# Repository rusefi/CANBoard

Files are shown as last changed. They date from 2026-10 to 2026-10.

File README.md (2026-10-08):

# CANBoard
CANBoard is a simple CAN enabled IO board, specifically designed to be used in devices like steering wheels/button boxes/panels/etc.

* 8 digital inputs
    * Ground switching
* 5 analog inputs
    * 5V max
* 4 digital outputs
    * Low side switch (open collector)
    * 0.5A max each
* STM32F303K8
* KiCad 7.0.0

# Goals
- Create a low cost device that my friends and I can use in our project cars
- Use components that are easily soldered by hand (hence 0805) and are preferably from my stock of frequently used parts (ex: LD1117S33CTR)
- Share my work with others for reference, inspiration or collaboration. 

If this project does help you in any way, I'd appreciate a message!

# [Store](https://dingo-electronics.square.site/product/canboard/3)

# Disclaimer
Please note that this product has been designed by a hobbyist, not a professional. It is intended for off-road and testing use only. Users should operate the product at their own discretion and risk. The designer explicitly disclaims any responsibility for damage or injury that may result from the use of this product.

# Schematic
[Schematic PDF](/Export/V2/CANBoard_HW_V2.pdf)

# DBC

DBC file can be found [here](https://github.com/corygrant/dingoFW/tree/master/dbc)

# BOM

[Interactive BOM](https://htmlpreview.github.io/?https://github.com/corygrant/CANBoard/blob/main/docs/bom/ibom.html)

# JLCPCB manufacturing export

With KiCad 10+ (`kicad-cli`) and Python 3 installed, run:

```bash
./bin/export_jlcpcb.sh
# Optional output directory:
./bin/export_jlcpcb.sh /path/to/output
```

The default output is the git-ignored `JLCPCB/` directory:

* `CANBoard-Gerbers.zip`: all four copper layers, masks, silkscreens, paste,
  outline and separate plated/non-plated Excellon drill files.
* `CANBoard-BOM.csv`: grouped by value, footprint and schematic `LCSC` field.
* `CANBoard-POS.csv`: component positions (CPL), in millimetres on both sides.

The BOM and POS contain matching populated SMD references. Through-hole parts,
logos, jumpers and other footprints without eligible positions are omitted.
Parts without an LCSC number remain in the assembly files with a warning.
Gerbers, drills and positions share the board's drill/place origin. Copper zones
are refilled during export without saving changes to the PCB.

The script works from any directory and does not depend on `hellen-one`.
Use `KICAD_CLI` or `PYTHON` to override executable paths. CSV headers follow
[JLCPCB's KiCad export guide](https://jlcpcb.com/help/article/how-to-generate-the-bom-and-centroid-file-from-kicad).
Rotations retain KiCad's orientation, normalized to 0–360 degrees; review part
matches and orientations in JLCPCB's assembly preview before ordering.

# Jumpers
**CAN Term** : Soldering this jumper enables the 120 ohm terminating resistor across CANL/CANH

**CAN ID Jumpers 1 and 2** : Soldering these jumpers allows different base CAN IDs to be selected when using multiple CANBoards in the same bus
| 1 | 2 | Base CAN ID (Hex)|
| --- | --- | ----- |
| Open | Open | 0x640 |
| Closed | Open | 0x650 |
| Open | Closed | 0x660 |
| Closed | Closed | 0x670 |

# Firmware
[dingoFW](https://github.com/corygrant/dingoFW)

# Updating Firmware
Use [Tag Connect TC2030 cable](https://www.tag-connect.com/product/tc2030-ctx-nl-stdc14-for-use-with-stm32-processors-with-stlink-v3) 

# Images
Top

Bottom

Connections

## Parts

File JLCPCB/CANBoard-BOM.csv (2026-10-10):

Comment | Designator | Footprint | LCSC Part #
10uF | C1,C2,C8 | C_0805_2012Metric | C15850
100nF | C3,C4,C7,C14,C17,C18,C19 | C_0805_2012Metric | C49678
22uF | C5,C6 | C_0805_2012Metric | C45783
10nF | C9,C10,C11,C12,C13,C21 | C_0805_2012Metric | C1710
27pF | C15,C16 | C_0805_2012Metric | C1808
4.7uF | C20 | C_0805_2012Metric | C1779
1uF | C22 | C_0805_2012Metric | C28323
LED_Small | D1 | LED_0805_2012Metric | C2900154
NUP2105LT1G | D2 | SOT-23-3 | C2890118
Ferrite_Bead_Small | FB1 | R_0805_2012Metric | C85840
5.6uH | L1 | Wuerth_LHMI | C467062
DMN2004WK | Q1,Q2,Q3,Q4 | SOT-323_SC-70 | C151011
30R | R1 | R_0805_2012Metric | C325808
52.3K | R2 | R_0805_2012Metric | C17740
10K | R3,R5,R6,R7,R8,R9,R10,R11,R12,R18,R19,R20,R21,R22,R24,R25,R26,R28,R29,R30,R31,R32,R33,R34,R35 | R_0805_2012Metric | C17414
120R | R4 | R_0805_2012Metric | C17437
4.7K | R13,R14,R15,R16,R17 | R_0805_2012Metric | C17673
1K | R23 | R_0805_2012Metric | C17513
120R 2W | R27 | R_2512_6332Metric | C19865
TPS56339DDCR | U1 | SOT-23-6 | C2071106
LD1117S33CTR | U2 | SOT-223 | C35879
MCP2562 | U3 | SOIC-8_3.9x4.9mm_P1.27mm | C191417
STM32F303K8T6 | U4 | LQFP-32_7x7mm_P0.8mm | C118318
8mHz | Y1 | Crystal_SMD_5032-2Pin_5.0x3.2mm | C144380

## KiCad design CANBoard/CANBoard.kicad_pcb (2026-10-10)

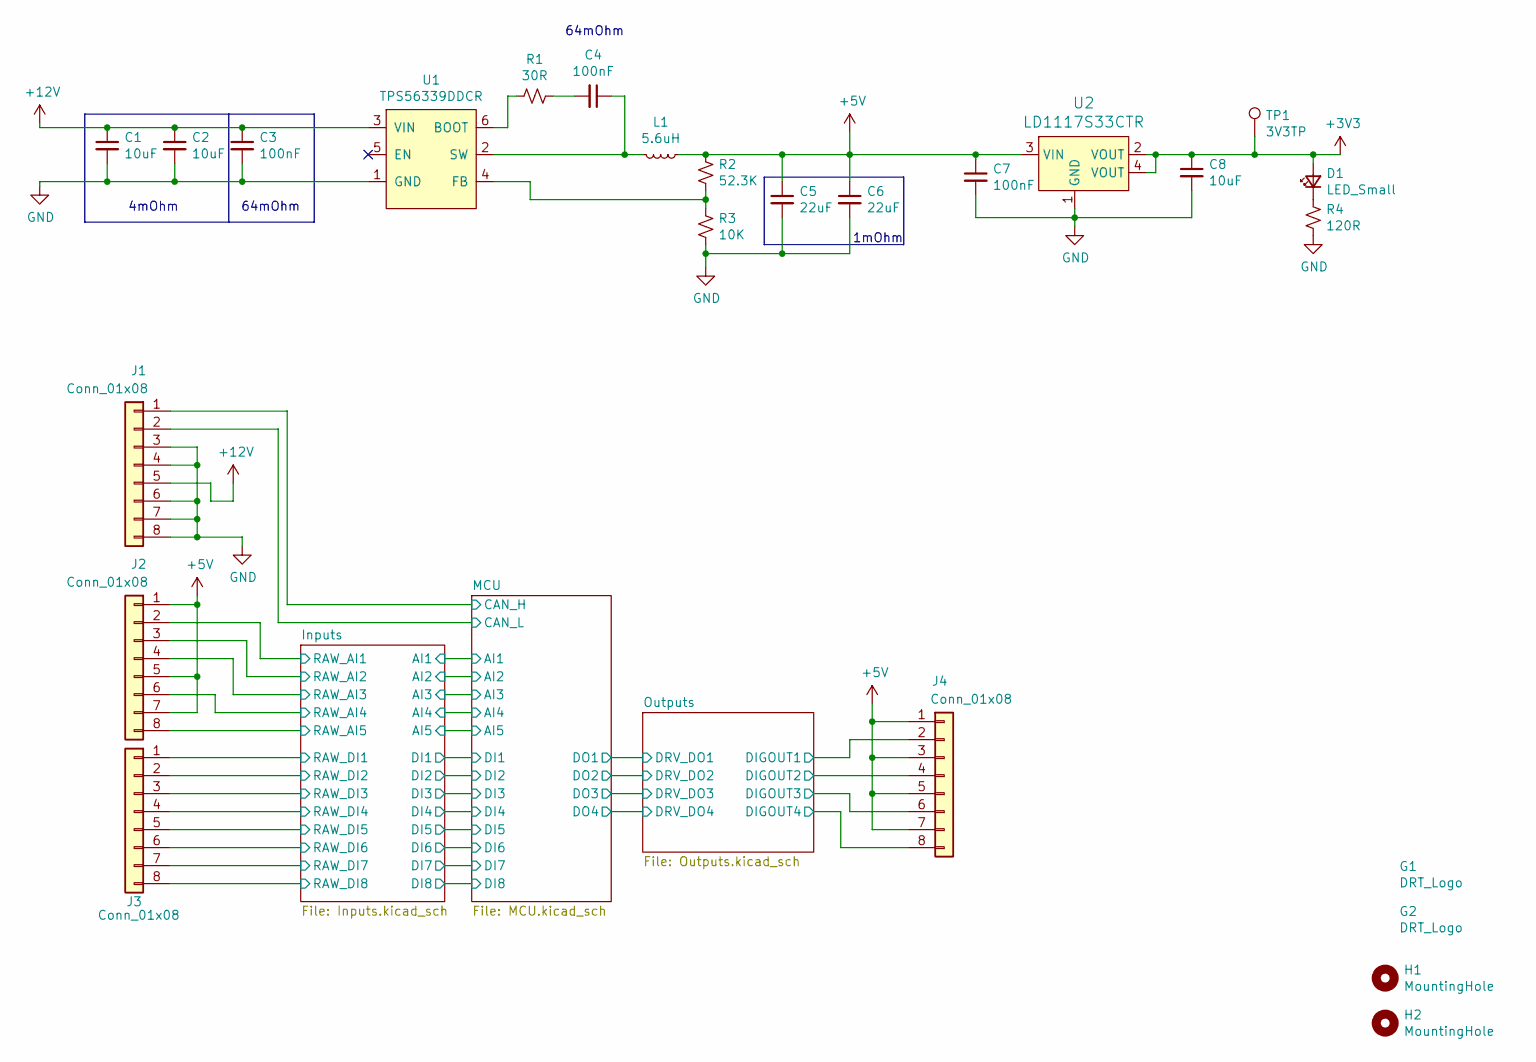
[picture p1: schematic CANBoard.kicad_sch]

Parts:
C1, C2, C8: 10uF; C_0805_2012Metric; Digi-Key_PN 490-10748-1-ND
C3, C4, C7: 100nF; C_0805_2012Metric; Digi-Key_PN 399-1169-1-ND
C5, C6: 22uF; C_0805_2012Metric; Digi-Key_PN 445-14560-1-ND
D1: LED_Small; LED_0805_2012Metric; Digi-Key_PN 475-2560-1-ND
G1: DRT_Logo; DRTLogo
G2: DRT_Logo; DingoFaceNoFill
H1, H2: MountingHole; MountingHole_3.2mm_M3_DIN965_Pad
J1, J2, J3, J4: Conn_01x08; PinHeader_1x08_P2.54mm_Vertical
L1: 5.6uH; Wuerth_LHMI; Digi-Key_PN 732-3339-1-ND
R1: 30R; R_0805_2012Metric; Digi-Key_PN RR12Q30DCT-ND
R2: 52.3K; R_0805_2012Metric; Digi-Key_PN P52.3KCCT-ND
R3: 10K; R_0805_2012Metric; Digi-Key_PN 311-10.0KCRDKR-ND
R4: 120R; R_0805_2012Metric; Digi-Key_PN 311-120CRCT-ND
TP1: 3V3TP; TestPoint_Pad_D1.0mm
U1: TPS56339DDCR; SOT-23-6; Digi-Key_PN 296-53568-1-ND
U2: LD1117S33CTR; SOT-223; MPN LD1117S33CTR; Digi-Key_PN 497-1241-1-ND

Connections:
+3V3: C8.1, D1.2 (A), TP1.1 (1_1), U2.2 (VOUT), U2.4 (VOUT); also elsewhere on the board
+5V: C5.1, C6.1, C7.1, J2.1, J2.5, J2.7, J4.1, J4.3, J4.5, J4.7, L1.1, R2.2, U2.3 (VIN); also elsewhere on the board
+12V: C1.1, C2.1, C3.1, J1.5, U1.3 (VIN)
/Inputs/RAW_AI1: J2.2; also elsewhere on the board
/Inputs/RAW_AI2: J2.3; also elsewhere on the board
/Inputs/RAW_AI3: J2.4; also elsewhere on the board
/Inputs/RAW_AI4: J2.6; also elsewhere on the board
/Inputs/RAW_AI5: J2.8; also elsewhere on the board
/Inputs/RAW_DI1: J3.1; also elsewhere on the board
/Inputs/RAW_DI2: J3.2; also elsewhere on the board
/Inputs/RAW_DI3: J3.3; also elsewhere on the board
/Inputs/RAW_DI4: J3.4; also elsewhere on the board
/Inputs/RAW_DI5: J3.5; also elsewhere on the board
/Inputs/RAW_DI6: J3.6; also elsewhere on the board
/Inputs/RAW_DI7: J3.7; also elsewhere on the board
/Inputs/RAW_DI8: J3.8; also elsewhere on the board
/MCU/CAN_H: J1.1; also elsewhere on the board
/MCU/CAN_L: J1.2; also elsewhere on the board
/Outputs/DIGOUT1: J4.2; also elsewhere on the board
/Outputs/DIGOUT2: J4.4; also elsewhere on the board
/Outputs/DIGOUT3: J4.6; also elsewhere on the board
/Outputs/DIGOUT4: J4.8; also elsewhere on the board
GND: C1.2, C2.2, C3.2, C5.2, C6.2, C7.2, C8.2, J1.3, J1.4, J1.6, J1.7, J1.8, R3.1, R4.1, U1.1 (GND), U2.1 (GND); also elsewhere on the board
unnamed: C4.2, R1.1
unnamed: D1.1 (K), R4.2
unnamed: R1.2, U1.6 (BOOT)
unnamed: R2.1, R3.2, U1.4 (FB)
unnamed: C4.1, L1.2, U1.2 (SW)

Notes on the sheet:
1mOhm
4mOhm
64mOhm

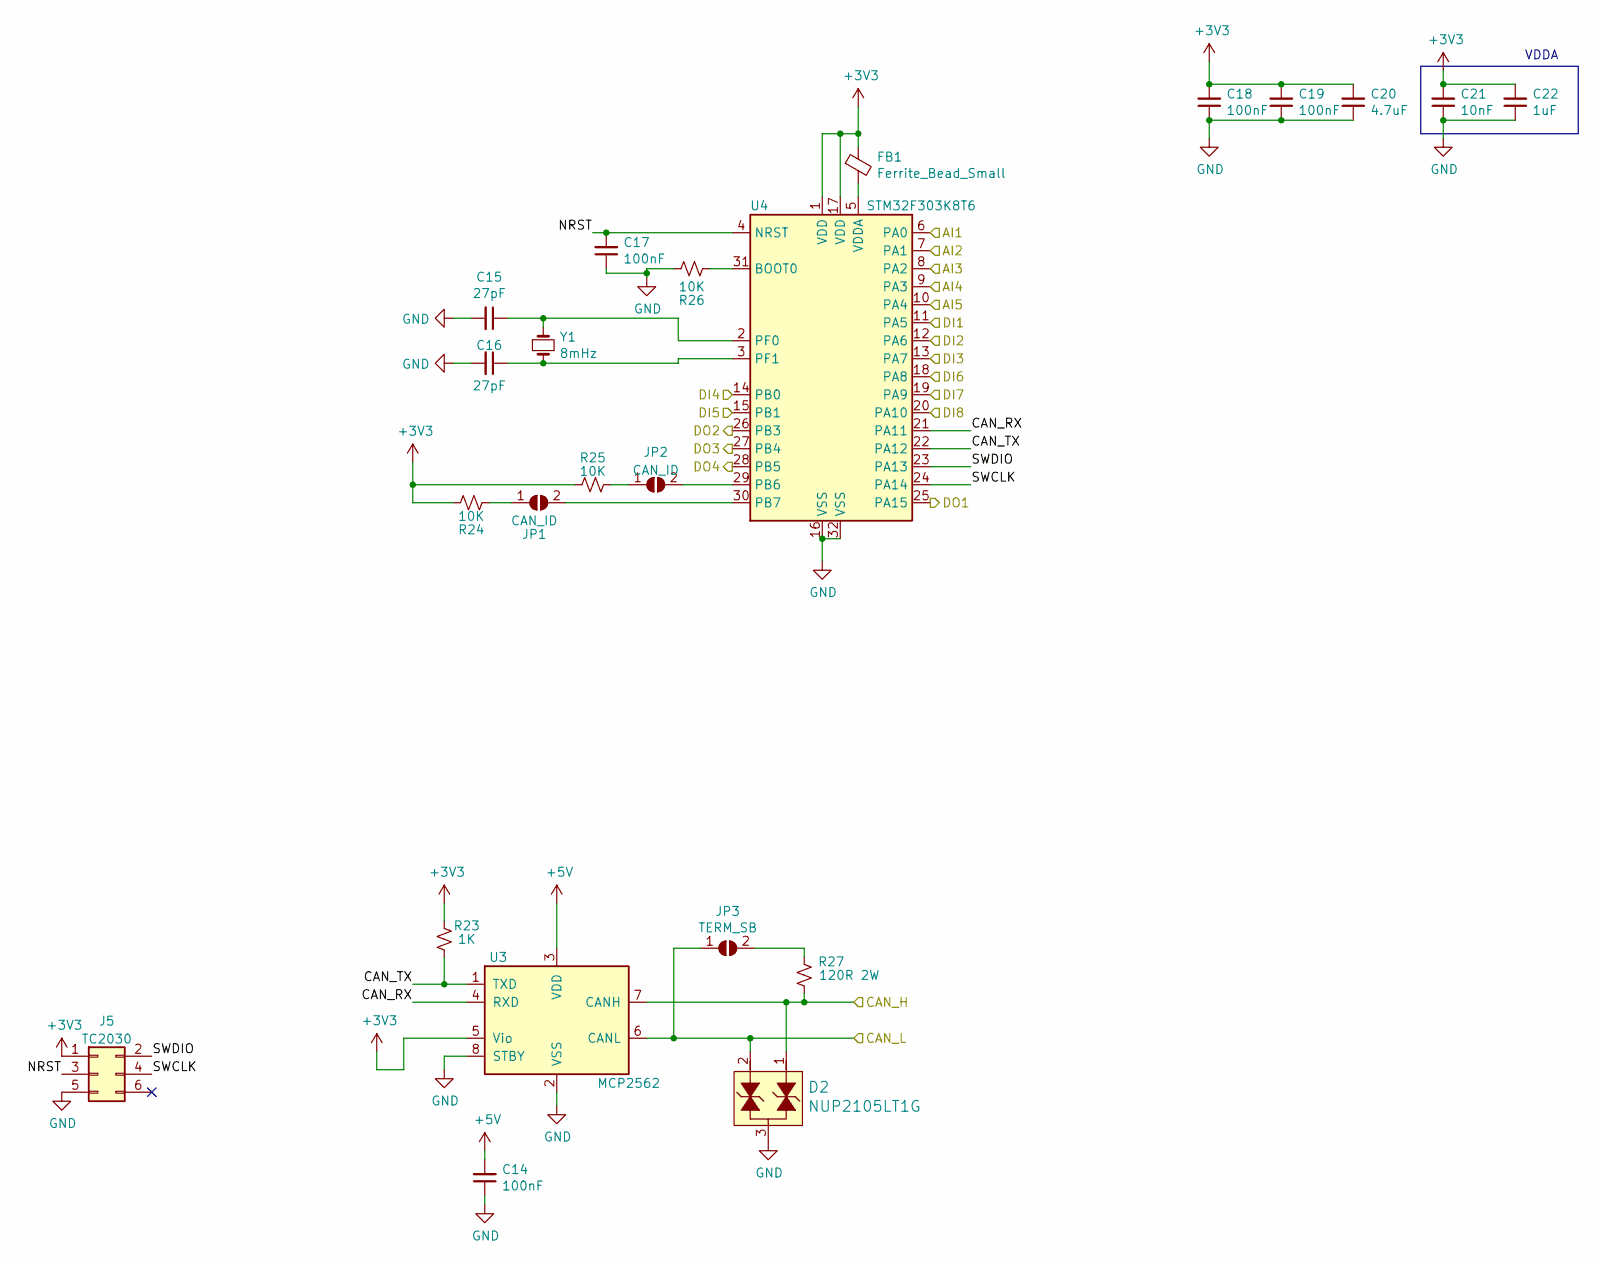
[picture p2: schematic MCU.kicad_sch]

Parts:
C14, C17, C18, C19: 100nF; C_0805_2012Metric; Digi-Key_PN 399-1169-1-ND
C15, C16: 27pF; C_0805_2012Metric; Digi-Key_PN 478-10518-1-ND
C20: 4.7uF; C_0805_2012Metric; Digi-Key_PN 1276-2873-1-ND
C21: 10nF; C_0805_2012Metric; Digi-Key_PN 311-1136-1-ND
C22: 1uF; C_0805_2012Metric; Digi-Key_PN 311-1365-1-ND
D2: NUP2105LT1G; SOT-23-3; MPN NUP2105LT1G; Digi-Key_PN NUP2105LT1GOSCT-ND
FB1: Ferrite_Bead_Small; R_0805_2012Metric; Digi-Key_PN 490-1054-1-ND
J5: TC2030; Tag-Connect_TC2030-IDC-NL_2x03_P1.27mm_Vertical
JP1, JP2: CAN_ID; SolderJumper-2_P1.3mm_Open_RoundedPad1.0x1.5mm
JP3: TERM_SB; SolderJumper-2_P1.3mm_Open_RoundedPad1.0x1.5mm
R23: 1K; R_0805_2012Metric; Digi-Key_PN 311-1.0KARCT-ND
R24, R25, R26: 10K; R_0805_2012Metric; Digi-Key_PN 311-10.0KCRDKR-ND
R27: 120R 2W; R_2512_6332Metric; Digi-Key_PN A116010CT-ND
U3: MCP2562; SOIC-8_3.9x4.9mm_P1.27mm; Digi-Key_PN MCP2562-H/SN-ND
U4: STM32F303K8T6; LQFP-32_7x7mm_P0.8mm; Digi-Key_PN 497-15828-ND
Y1: 8mHz; Crystal_SMD_5032-2Pin_5.0x3.2mm; Digi-Key_PN 535-10630-1-ND

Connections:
+3V3: C18.2, C19.2, C20.2, C21.2, C22.2, FB1.1, J5.1, R23.2, R24.2, R25.2, U3.5 (Vio), U4.1 (VDD), U4.17 (VDD); also elsewhere on the board
+5V: C14.2, U3.3 (VDD); also elsewhere on the board
/Inputs/AI1: U4.6 (PA0); also elsewhere on the board
/Inputs/AI2: U4.7 (PA1); also elsewhere on the board
/Inputs/AI3: U4.8 (PA2); also elsewhere on the board
/Inputs/AI4: U4.9 (PA3); also elsewhere on the board
/Inputs/AI5: U4.10 (PA4); also elsewhere on the board
/Inputs/DI1: U4.11 (PA5); also elsewhere on the board
/Inputs/DI2: U4.12 (PA6); also elsewhere on the board
/Inputs/DI3: U4.13 (PA7); also elsewhere on the board
/Inputs/DI4: U4.14 (PB0); also elsewhere on the board
/Inputs/DI5: U4.15 (PB1); also elsewhere on the board
/Inputs/DI6: U4.18 (PA8); also elsewhere on the board
/Inputs/DI7: U4.19 (PA9); also elsewhere on the board
/Inputs/DI8: U4.20 (PA10); also elsewhere on the board
/MCU/CAN_H: D2.1, R27.1, U3.7 (CANH); also elsewhere on the board
/MCU/CAN_L: D2.2, JP3.1 (A), U3.6 (CANL); also elsewhere on the board
/MCU/CAN_RX: U3.4 (RXD), U4.21 (PA11)
/MCU/CAN_TX: R23.1, U3.1 (TXD), U4.22 (PA12)
/MCU/DO1: U4.25 (PA15); also elsewhere on the board
/MCU/DO2: U4.26 (PB3); also elsewhere on the board
/MCU/DO3: U4.27 (PB4); also elsewhere on the board
/MCU/DO4: U4.28 (PB5); also elsewhere on the board
/MCU/NRST: C17.2, J5.3, U4.4 (NRST)
/MCU/SWCLK: J5.4, U4.24 (PA14)
/MCU/SWDIO: J5.2, U4.23 (PA13)
GND: C14.1, C15.2, C16.2, C17.1, C18.1, C19.1, C20.1, C21.1, C22.1, D2.3, J5.5, R26.2, U3.2 (VSS), U3.8 (STBY), U4.16 (VSS), U4.32 (VSS); also elsewhere on the board
unnamed: JP1.1 (A), R24.1
unnamed: JP1.2 (B), U4.30 (PB7)
unnamed: JP2.1 (A), R25.1
unnamed: JP2.2 (B), U4.29 (PB6)
unnamed: JP3.2 (B), R27.2
unnamed: R26.1, U4.31 (BOOT0)
unnamed: C15.1, U4.2 (PF0), Y1.1
unnamed: C16.1, U4.3 (PF1), Y1.2
unnamed: FB1.2, U4.5 (VDDA)

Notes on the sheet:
VDDA

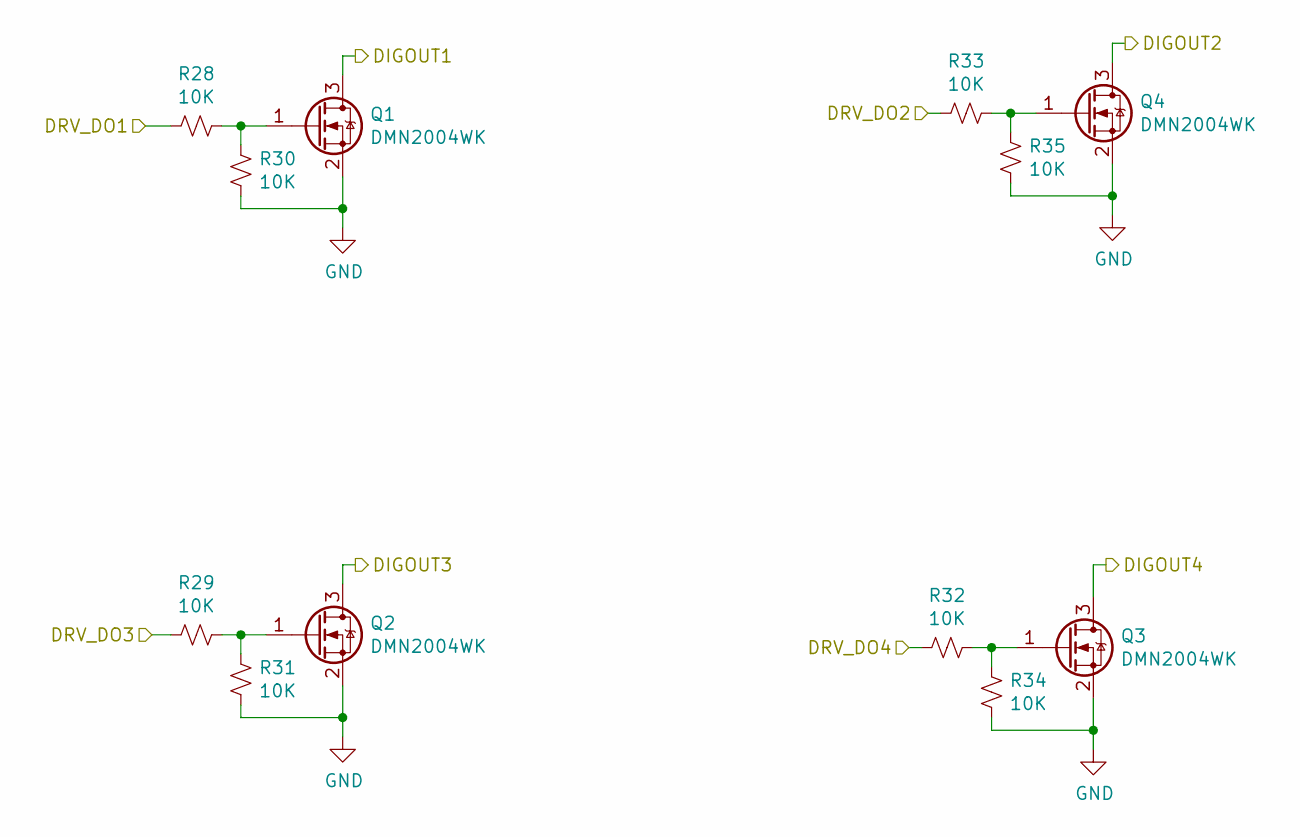
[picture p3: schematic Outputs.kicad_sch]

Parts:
Q1, Q2, Q3, Q4: DMN2004WK; SOT-323_SC-70; Digi-Key_PN DMN2004WKDICT-ND
R28, R29, R30, R31, R32, R33, R34, R35: 10K; R_0805_2012Metric; Digi-Key_PN 311-10.0KCRDKR-ND

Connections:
/MCU/DO1: R28.2; also elsewhere on the board
/MCU/DO2: R33.2; also elsewhere on the board
/MCU/DO3: R29.2; also elsewhere on the board
/MCU/DO4: R32.2; also elsewhere on the board
/Outputs/DIGOUT1: Q1.3 (D); also elsewhere on the board
/Outputs/DIGOUT2: Q4.3 (D); also elsewhere on the board
/Outputs/DIGOUT3: Q2.3 (D); also elsewhere on the board
/Outputs/DIGOUT4: Q3.3 (D); also elsewhere on the board
GND: Q1.2 (S), Q2.2 (S), Q3.2 (S), Q4.2 (S), R30.1, R31.1, R34.1, R35.1; also elsewhere on the board
unnamed: Q1.1 (G), R28.1, R30.2
unnamed: Q2.1 (G), R29.1, R31.2
unnamed: Q3.1 (G), R32.1, R34.2
unnamed: Q4.1 (G), R33.1, R35.2

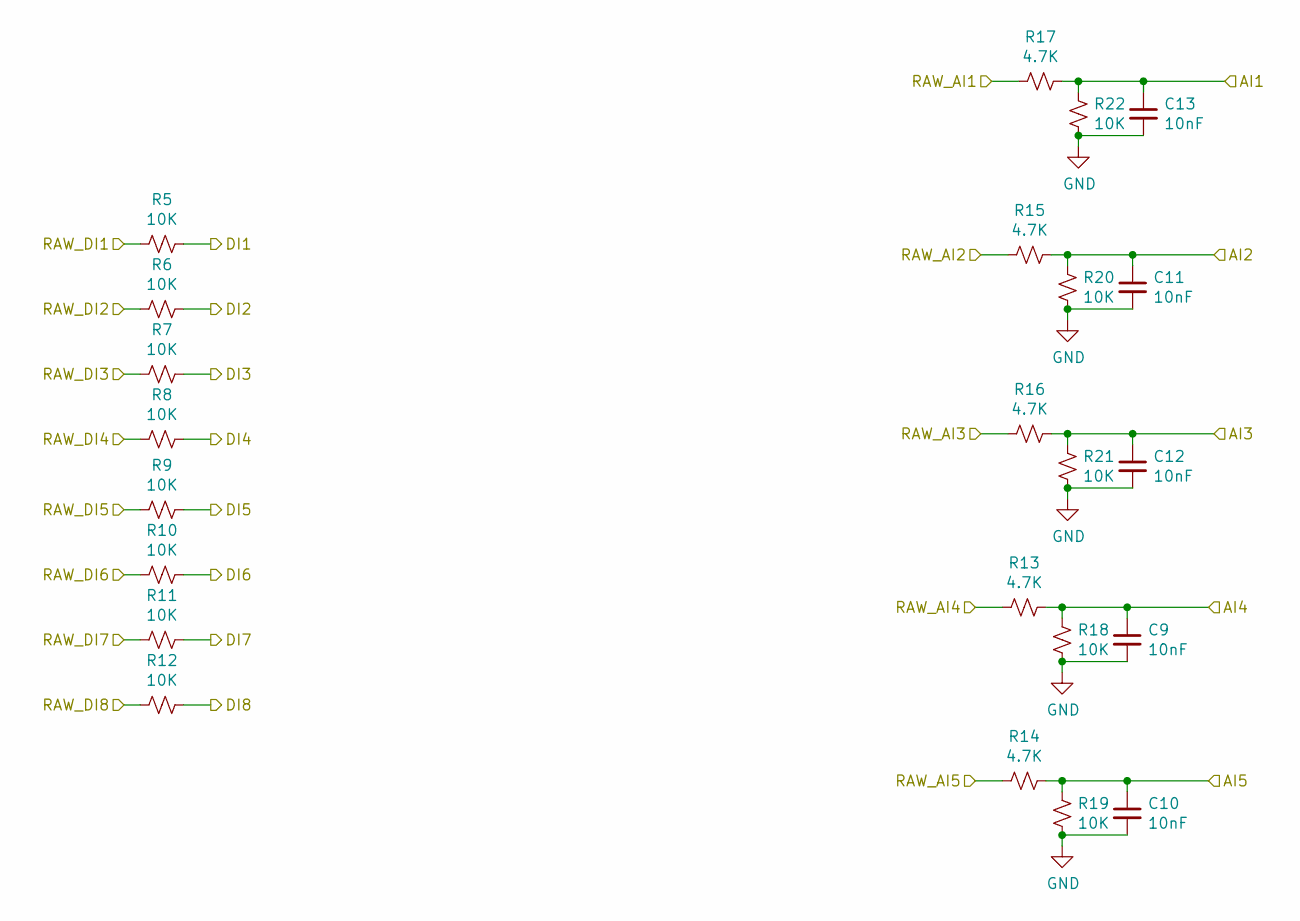
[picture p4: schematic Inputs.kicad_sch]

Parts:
C9, C10, C11, C12, C13: 10nF; C_0805_2012Metric; Digi-Key_PN 311-1136-1-ND
R5, R6, R7, R8, R9, R10, R11, R12, R18, R19, R20, R21, R22: 10K; R_0805_2012Metric; Digi-Key_PN 311-10.0KCRDKR-ND
R13, R14, R15, R16, R17: 4.7K; R_0805_2012Metric; Digi-Key_PN 311-4.70KCRCT-ND

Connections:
/Inputs/AI1: C13.1, R17.1, R22.2; also elsewhere on the board
/Inputs/AI2: C11.1, R15.1, R20.2; also elsewhere on the board
/Inputs/AI3: C12.1, R16.1, R21.2; also elsewhere on the board
/Inputs/AI4: C9.1, R13.1, R18.2; also elsewhere on the board
/Inputs/AI5: C10.1, R14.1, R19.2; also elsewhere on the board
/Inputs/DI1: R5.1; also elsewhere on the board
/Inputs/DI2: R6.1; also elsewhere on the board
/Inputs/DI3: R7.1; also elsewhere on the board
/Inputs/DI4: R8.1; also elsewhere on the board
/Inputs/DI5: R9.1; also elsewhere on the board
/Inputs/DI6: R10.1; also elsewhere on the board
/Inputs/DI7: R11.1; also elsewhere on the board
/Inputs/DI8: R12.1; also elsewhere on the board
/Inputs/RAW_AI1: R17.2; also elsewhere on the board
/Inputs/RAW_AI2: R15.2; also elsewhere on the board
/Inputs/RAW_AI3: R16.2; also elsewhere on the board
/Inputs/RAW_AI4: R13.2; also elsewhere on the board
/Inputs/RAW_AI5: R14.2; also elsewhere on the board
/Inputs/RAW_DI1: R5.2; also elsewhere on the board
/Inputs/RAW_DI2: R6.2; also elsewhere on the board
/Inputs/RAW_DI3: R7.2; also elsewhere on the board
/Inputs/RAW_DI4: R8.2; also elsewhere on the board
/Inputs/RAW_DI5: R9.2; also elsewhere on the board
/Inputs/RAW_DI6: R10.2; also elsewhere on the board
/Inputs/RAW_DI7: R11.2; also elsewhere on the board
/Inputs/RAW_DI8: R12.2; also elsewhere on the board
GND: C9.2, C10.2, C11.2, C12.2, C13.2, R18.1, R19.1, R20.1, R21.1, R22.1; also elsewhere on the board

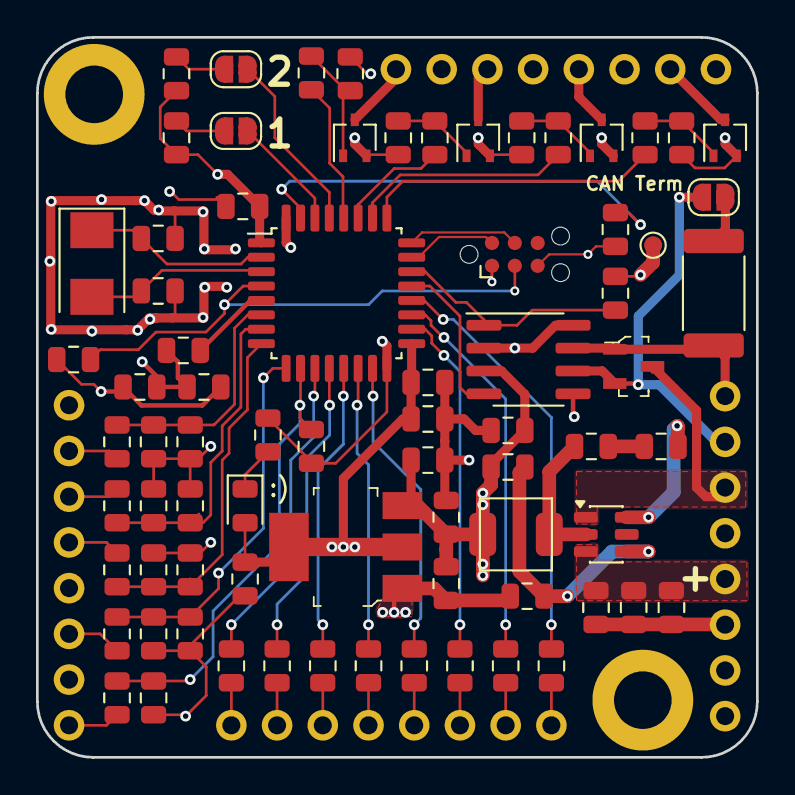
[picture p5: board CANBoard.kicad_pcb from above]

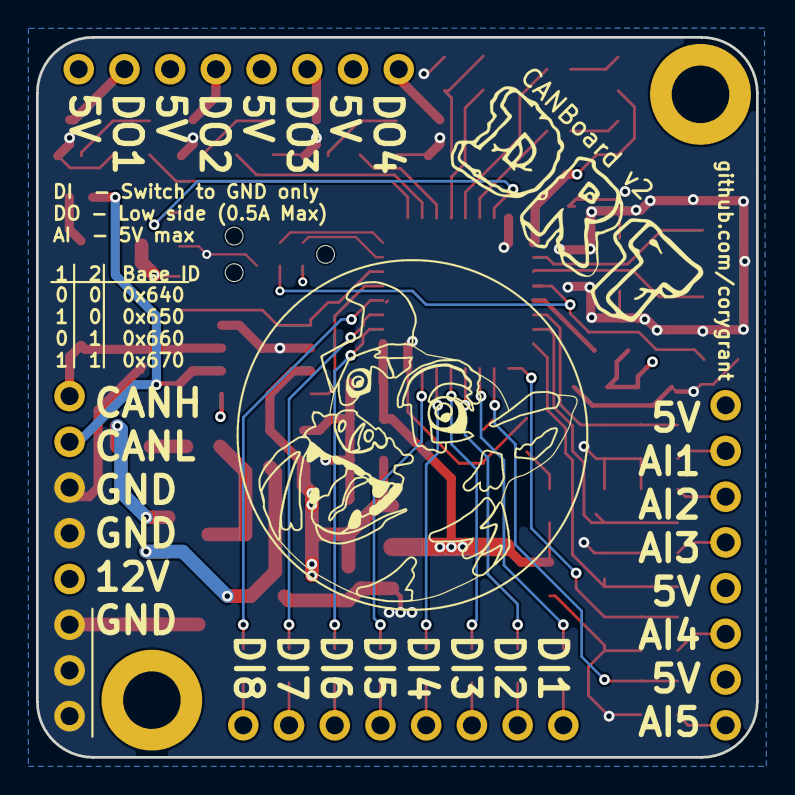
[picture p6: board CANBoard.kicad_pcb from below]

Board: 4 copper layers, 40.0 x 40.0 mm, 83 parts (2 on the bottom side), 63 nets.
